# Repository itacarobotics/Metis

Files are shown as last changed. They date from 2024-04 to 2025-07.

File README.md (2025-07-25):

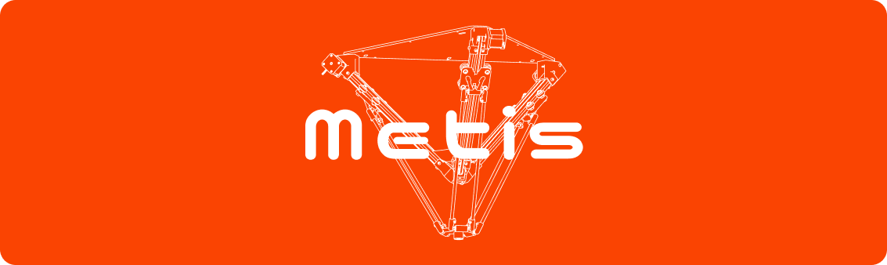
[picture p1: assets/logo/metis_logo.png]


# About
Welcome to the Metis repository! This project is dedicated to the design, manufacture, and control of a delta robot, entirely from scratch.

# Key Features
- *Custom 3D Printed Components*
- *URDF Description of the robot*
- *ROS2 Integration*
- *Micro-ROS on ESP32*

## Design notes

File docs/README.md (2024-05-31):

# Documentation

## Mechanics
All mechanical components have been designed from scratch using computer-aided design (CAD) software, specifically Autodesk Inventor 2024. Additionally, some components have been topological optimized with the software Autodesk Fusion. This process aims to optimize the material layout of mechanical components, reducing mass while increasing stiffness.

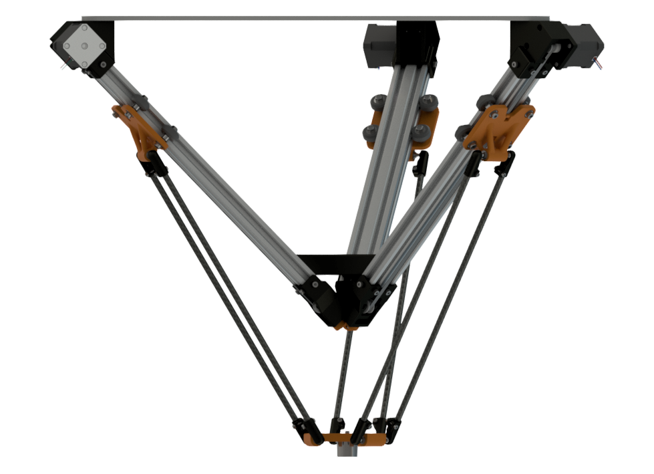
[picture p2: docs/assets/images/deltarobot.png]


#### Actuation
Industrial delta robots commonly have a revolute actuation, which enables fast movements at the cost of larger motors, given the mechanical disadvantage of a longer arm. For this project, the actuation is performed with belt-driven prismatic joints. This design choice allows for a more compact and cost-effective drivetrain, maintaining rigidity and precision.

#### Prismatic Joints
Designing the linear rails of the prismatic joint presented one of the biggest challenges in the mechanical design process. Traditional options like linear ball bearings and linear bearing rails were deemed too heavy and expensive, while polymeric bushings introduced excessive friction. The solution implemented is a rail system with four V-shaped profile wheels rolling within the cavities of an aluminum profile, a mechanism commonly found in 3D printers. This system ensures smooth and stiff motion.

#### Spherical Joints
Each prismatic joint features two spherical pins bolted onto a threaded aluminum shaft. These shafts are held in place by a topologically optimized structure, enhancing both weight distribution and stiffness. A spherical joint, designed to fit with minimal clearance onto the spherical pin, is manufactured using resin additive manufacturing for a refined surface finish, as opposed to Fusion Deposition Modeling (FDM) technology.

#### Workspace
While designing an industrial robot, it is essential to define its workspace. The total working volume that the end-effector can reach is directly influenced by the lengths of the robot's links and the strokes of its joints. To establish the kinematic properties of the robot, a Python script has been created to visualize the workspace of the delta robot.

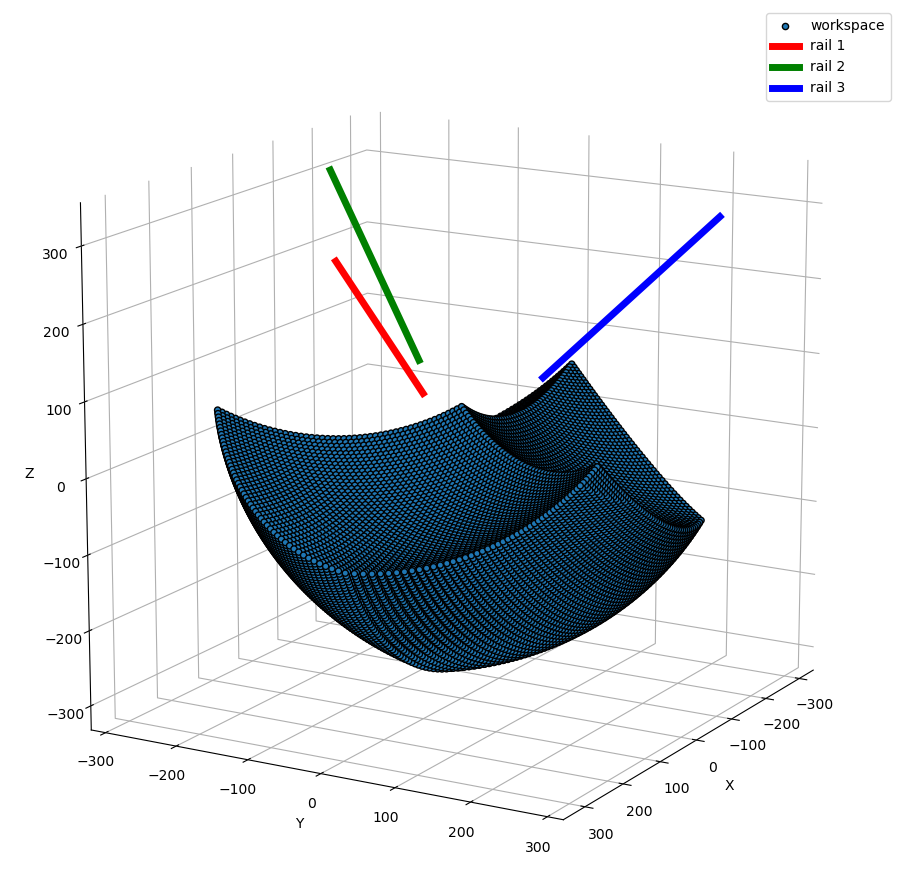
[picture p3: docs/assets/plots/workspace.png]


## Electronics
The electronics bridges the gap between the high level control system and the mechanics. The motherboard of the robot communicates to the computer (master) via USB or WIFI and directly controls all sensors, actuators and other peripherals of the robot.
Given limited time for the development of this project, an open-source motherboard ([MKS-DLC32](https://github.com/makerbase-mks/MKS-DLC32)), developed for desktop engraving machines, has been implemented.

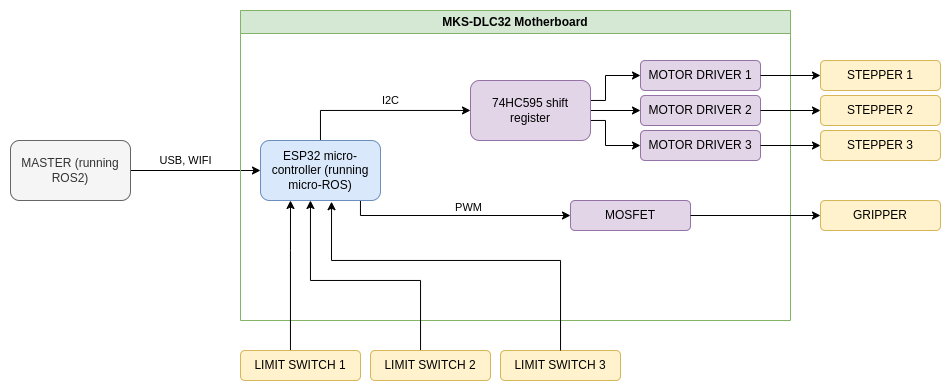
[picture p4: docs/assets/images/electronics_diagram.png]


#### Micro-controller
The ESP32 micro-controller is a low-power micro-controller. However, given its limited computational power, its main task is just to execute robot commands received by the main computer and directly control the low-level interfaces.

#### Motors and Motor Driver
The micro-controller has limited GPIO (General Pourpose Input Output). To solve this problem, the motherboard controls the stepper motor drivers with a shift register IO expander (74HC595). Stepper motors used for this project are NEMA17 with 60 Ncm of torque, which satisfy the project requirements.

#### Other Peripherals
The motherboard includes several peripheral interfaces essential for the robot's functionality. These peripherals include ports for limit switches and a MOSFET (Metal-Oxide-Semiconductor Field-Effect Transistor). Limit switches are used to set the zero position of the robot, when turned on. The MOSFET is integrated to enable and disable the electromagnetic gripper from the micro-controller.

## Software Architecture
The software of the delta robot is decentralized over two devices, the main computer, which is responsible for the heavier computational tasks and the micro-controller, which is responsible for controlling actuators, reading sensors and other peripherals. Overall the software architecture can be subdivided into three main sections

- High-level interfaces
- Robot controller middle-ware
- Low-level firmware

#### High-Level Interface
The high-level interface is composed of all nodes the user can use to interact with the robot. For instance, the graphical user interface (GUI) helps the user control the position of the robot or, open and close the gripper. Another useful method for programming tasks of an industrial robot is the G-Code. It is a language commonly used for CNC machines or 3D printers and it consists of a set of instruction that the robot has to execute. Furthermore, computer vision algorithms can be implemented for an automated pick and place application.

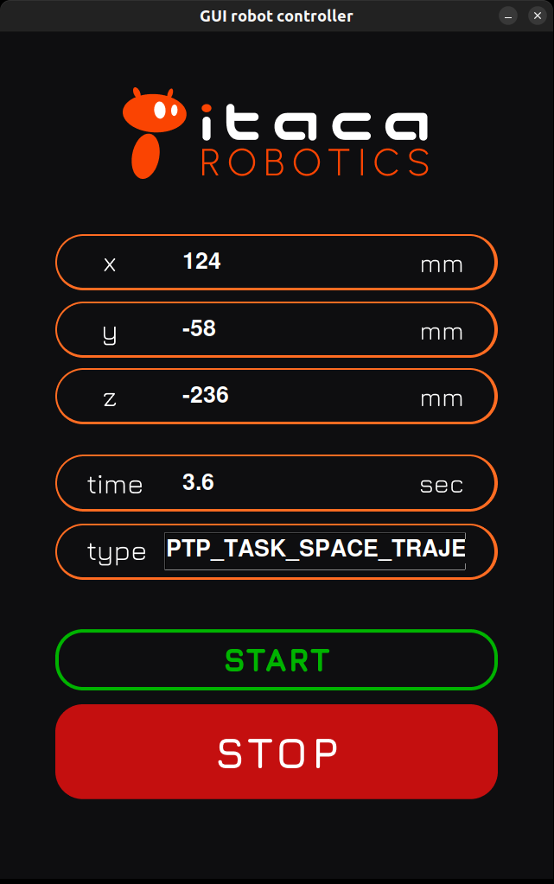
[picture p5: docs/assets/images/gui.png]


#### Middle-Ware
The middle-ware robot controller is mainly responsible for handling incoming tasks, managing exceptions and computing trajectory planning and inverse geometry. It is made up of the "task scheduler" and the "robot controller" ROS2 nodes. The first one takes all incoming tasks from the high-level interfaces and add them to a queue. Once the robot is ready, the task scheduler sends a new task from the queue to the robot controller node. This last computes the robot movements needed to accomplish the desired task and sends them to the micro-controller via USB or WIFI.

#### Low-Level Firmware
The low-level firmware runs on an ESP32 micro-controller and is mainly responsible for executing commands sent by the robot controller node. In order to integrate the micro-controller with the ROS2 environment, the firmware has been developed using the micro-ROS framework.
The micro-controller directly controls the stepper motors, the gripper and reads the state of the limit switches. After having completed the task, the micro-controller sends an acknowledgment (ack) feedback to the robot controller node, which accordingly sets the new state of the robot.

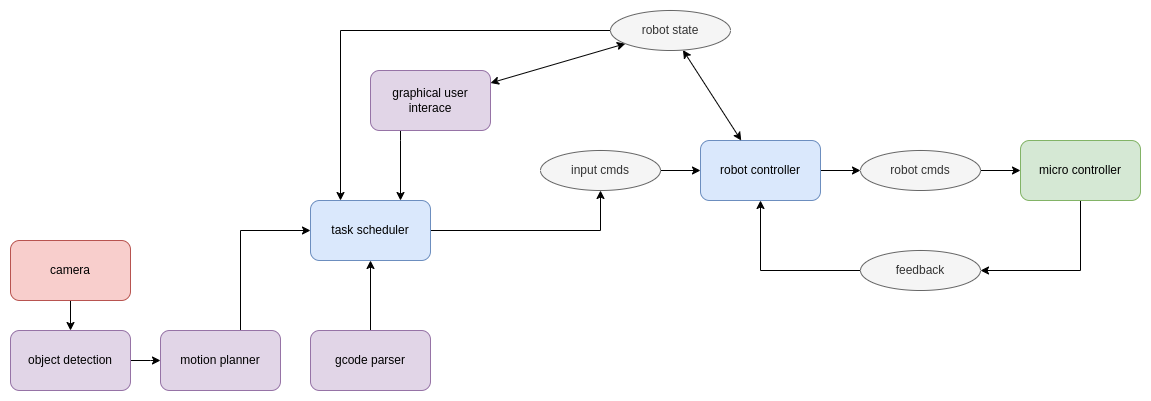
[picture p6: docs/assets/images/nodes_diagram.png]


## Trajectory Planning
For trajectories planned in task space, the path of the end-effector is interpolated with multiple via-points, whose the robot follows along its movement.
For this project, the path has been linearly interpolated by the function $\theta(s)$, hence the path describes a straight line from $X_0$ to $X_f$

$\theta(s) = X_0 + s \cdot (X_f-X_0), \qquad s \in [0, 1]$

The parameter $s$ is then remapped to a time scaling function in order to better control velocity and its derivatives along the path. The function $s(t)$ is interpolated with a fifth-order polynomial

$q(t) = a_0 + a_1 \cdot t + a_2 \cdot t^2 + a_3 \cdot t^3 + a_4 \cdot t^4 + a_5 \cdot t^5 \qquad t \in [0, T_f]$

In this case, the system of differential equations is

$q(0) = 0, \quad \dot{q}(0) = 0, \quad \ddot{q}(0) = 0 $
$q(T_f) = 1, \quad \dot{q}(T_f) = 0, \quad \ddot{q}(T_f) = 0 $

The closed form solution is

$a_0 = q_0, \quad a_1 = 0, \quad a_2 = 0 $
$a_3 =  \frac{10}{{T_f^3}}, \quad a_4 =  -\frac{15}{{T_f^4}}, \quad a_5 =  \frac{6}{{T_f^5}}$

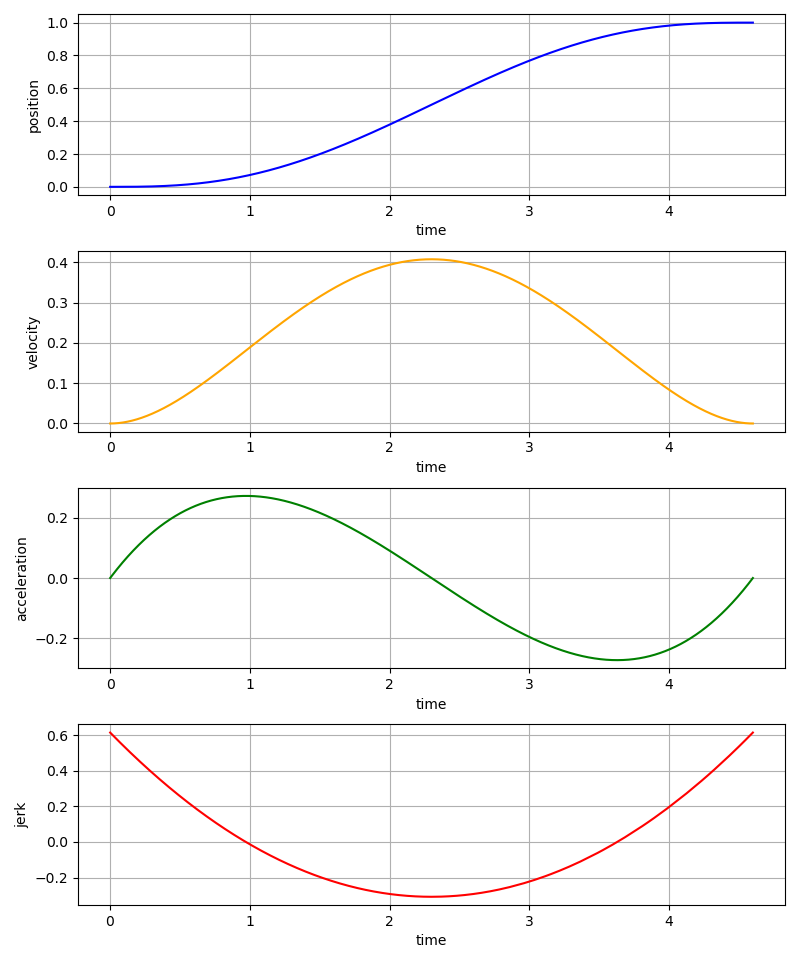
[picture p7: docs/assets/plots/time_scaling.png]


The total time of travel $T_f$ is calculated by setting joint's velocity and acceleration constraints.
Finally, inverse geometry is computed for each via point, resulting a joint trajectory.

## Inverse Geometry
The inverse geometry involves finding the joint angles that correspond to a desired end-effector position and orientation. 
The numerical inverse geometry of a delta robot, and many other robot arms, is a non linear optimization problem, which is solved over multiple iterations refining the initial guess for the joint angles, until a solution that minimizes the error between the desired and actual end-effector positions is found.
Overall, the problem admits a solution if the desired end-effector position is within the workspace of the robot. However, if a solution exists, there might be multiple or even infinite solutions.

In particular, if the problem admits a solution, it can be solved by minimizing the cost function $c(q)$, where, $f(q)$ is the forward geometry function and $p_d$ is the desired end-effector position. The goal is to find $q$ such that $f(q) \approx p_d$.

$c(q) = ||p_d - f(q)||$
For this project, the optimization problem has been solved with the Gauss-Newton algorithm, which starts with an initial guess $q_0$ and iterates as follows:

1. Compute the error vector  $e = p_d - f(q_i)$

2. Linearize the forward geometry function $f(q_i)$ around the current guess $q_i$ to obtain the Jacobian matrix $J(q_i)$.

3. Compute the step $\Delta q_i$ using the formula: 
$J^\dagger = J(q_i)^T J(q_i) + \lambda I, \quad \lambda \propto 10^{-2}$
$\Delta q_i = (J^\dagger)^{-1} J(q_i)^T e$

*Where* $J^\dagger$ *is the regularized pseudo-inverse of the Jacobian, which makes the matrix always invertible and positive.*

4. Update the guess:
$q_{i+1} = q_i + \Delta q_i$

5. Repeat steps 1-4 until convergence criteria are met, such as the error $||e||$ falling below a threshold or the change in $q_i$ falling below a threshold.

The cost function is a non-convex function, which means, it has at least one minimum. However, the algorithm may converge to a local minimum depending on the initial guess and the characteristics of the problem.

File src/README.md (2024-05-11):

# How to navigate the code
## /src/deltarobot
Middle-ware nodes and classes, runs ROS2 (on laptop)
- configuration file
- robot controller (node)
    - delta robot (class)
        - inverse geometry (class)
        - trajectroy generator (class)
- task scheduler (node)

## /src/deltarobot_inputs
High-level nodes to interact with the robot, runs ROS2 (on laptop)
- graphical user interface (node)
- gcode parser (node)
- template (node), for adding new features

## /src/firmware_esp32
Low-level firmware, runs 
[micro-ROS](https://github.com/micro-ROS/micro_ros_platformio) 
(on ESP32 microcontroller)
- micro-ROS init
- callback functions
- stepper motors driver

## /src/deltarobot_description
URDF description of the robot
- complete robot description (for visualizer)
- single closed chain description (for inverse geometry)

## /src/deltarobot_utils
Deprecated as last update.

## /src/micro_ros_setup
Used to setup the micro-ROS environment 
([help](https://github.com/micro-ROS/micro_ros_platformio))
(on ESP32 microcontroller)

## /src/uros
The actual micro-ROS agent 
([help](https://github.com/micro-ROS/micro_ros_platformio))
(on ESP32 microcontroller)

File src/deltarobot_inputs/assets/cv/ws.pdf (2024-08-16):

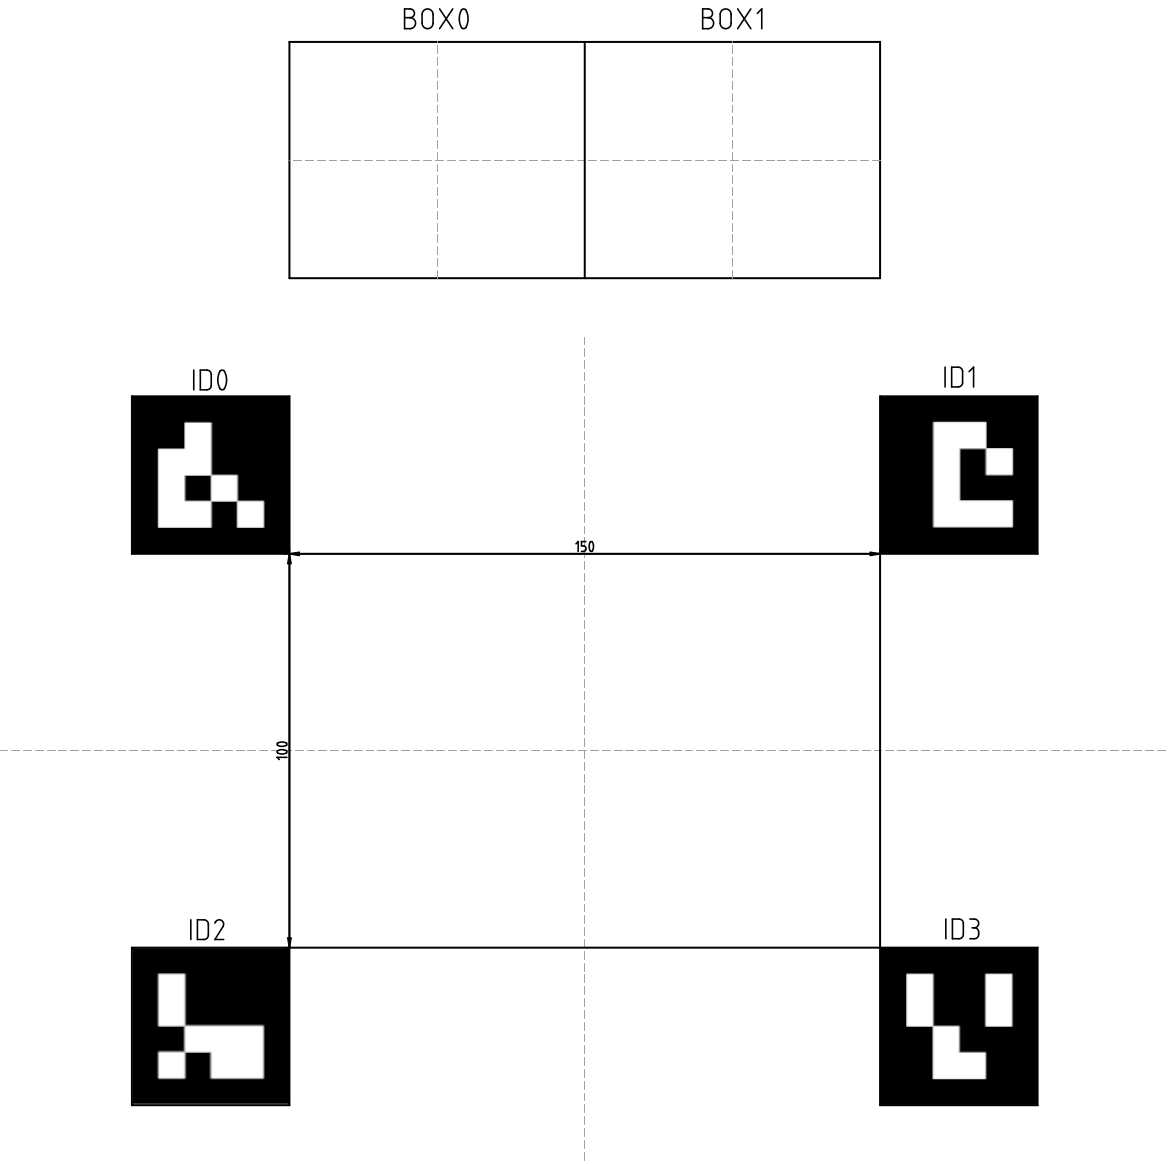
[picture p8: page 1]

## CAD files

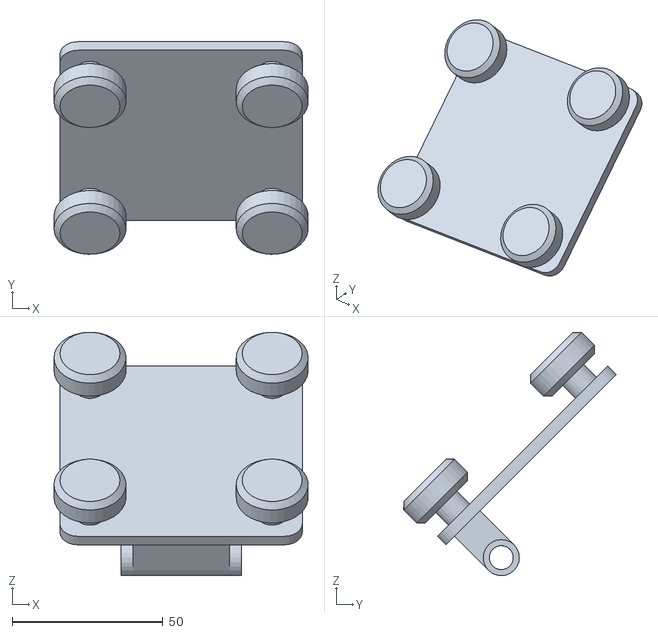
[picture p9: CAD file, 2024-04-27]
src/deltarobot_description/meshes/carriage.stl
84.3 x 70.6 x 80.8

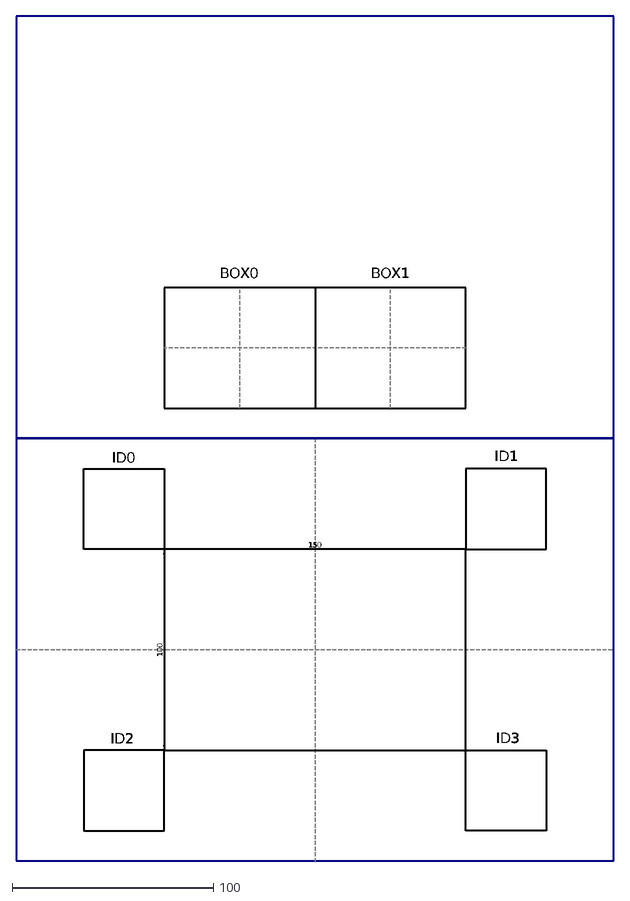
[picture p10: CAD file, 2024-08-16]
src/deltarobot_inputs/assets/cv/ws_base_A4.dxf
BOX0
BOX1
ID0
ID1
ID2
ID3
150
100

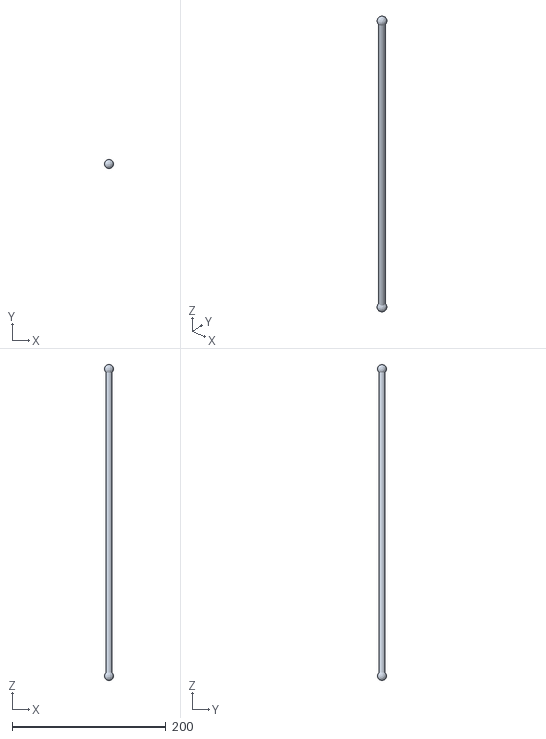
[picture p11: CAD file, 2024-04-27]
src/deltarobot_description/meshes/link.stl
12.0 x 11.4 x 411.7

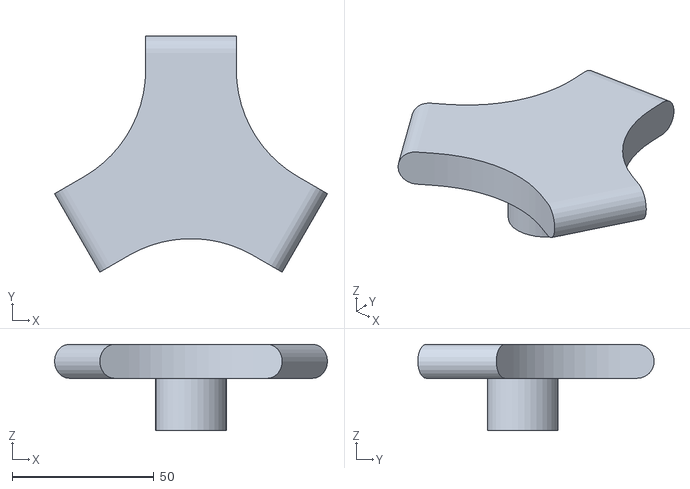
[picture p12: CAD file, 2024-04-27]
src/deltarobot_description/meshes/end_effector.stl
96.4 x 83.5 x 30.5

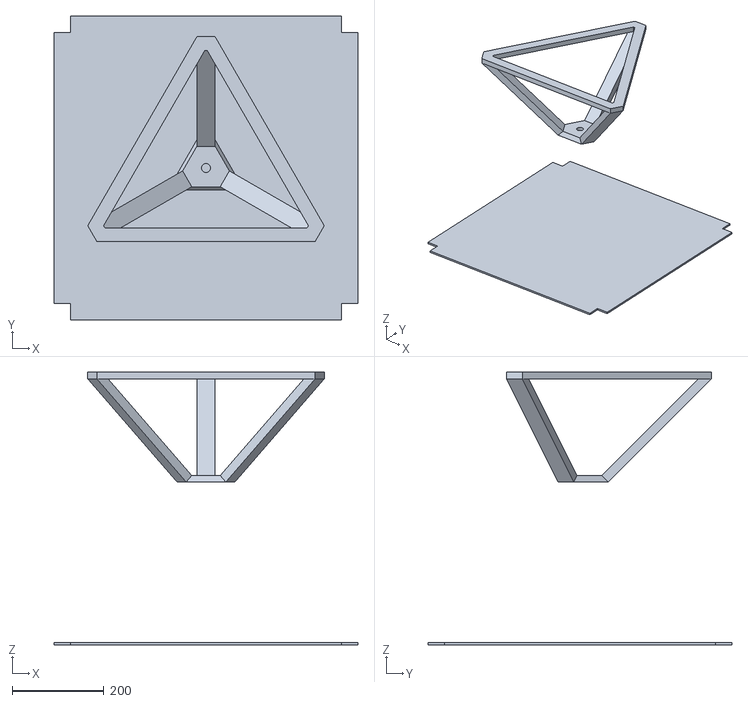
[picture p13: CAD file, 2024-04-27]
src/deltarobot_description/meshes/rails.stl
664.0 x 664.0 x 596.1

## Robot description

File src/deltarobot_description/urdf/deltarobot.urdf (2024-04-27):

<?xml version="1.0"?>
<robot name="deltarobot">

    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
    <link name="rails_link">
        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
    </link>
    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
    <link name="carriage_1_link">
        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
    </link>

    <joint name="carriage_1_joint" type="prismatic">
        <origin xyz="0. 0. 0." rpy="0 0 0"/>
        <parent link="rails_link"/>
        <child link="carriage_1_link"/>
        <axis xyz="0 1 1"/>
        <limit lower="0" upper="0" velocity="0" effort="0"/> 
    </joint>
    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
    <link name="rod_1a_link_virtual">
    </link>

    <link name="rod_1a_link">
        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
    </link>

    <joint name="rod_1a_x_joint" type="revolute">
        <origin xyz="25 0. 0." rpy="0 0 0"/>
        <parent link="carriage_1_link"/>
        <child link="rod_1a_link_virtual"/>
        <axis xyz="1 0 0"/>
        <limit lower="0" upper="0" velocity="0" effort="0"/> 
    </joint>

    <joint name="rod_1a_y_joint" type="revolute">
        <origin xyz="0. 0. 0." rpy="0 0 0"/>
        <parent link="rod_1a_link_virtual"/>
        <child link="rod_1a_link"/>
        <axis xyz="0 1 0"/>
        <limit lower="0" upper="0" velocity="0" effort="0"/> 
    </joint>
    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
    <link name="rod_1b_link_virtual">
    </link>

    <link name="rod_1b_link">
        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
    </link>

    <joint name="rod_1b_x_joint" type="revolute">
        <origin xyz="-25 0. 0." rpy="0 0 0"/>
        <parent link="carriage_1_link"/>
        <child link="rod_1b_link_virtual"/>
        <axis xyz="1 0 0"/>
        <limit lower="0" upper="0" velocity="0" effort="0"/> 
    </joint>

    <joint name="rod_1b_y_joint" type="revolute">
        <origin xyz="0. 0. 0." rpy="0 0 0"/>
        <parent link="rod_1b_link_virtual"/>
        <child link="rod_1b_link"/>
        <axis xyz="0 1 0"/>
        <limit lower="0" upper="0" velocity="0" effort="0"/> 
    </joint>
    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
    <link name="rod_1_end_effector_link">
    </link>

    <joint name="rod_1_end_effector_joint" type="fixed">
        <origin xyz="0 0 -400"/>
        <parent link="rod_1a_link"/>
        <child link="rod_1_end_effector_link"/>
    </joint>
    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
    <link name="carriage_2_link">
        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
    </link>

    <joint name="carriage_2_joint" type="prismatic">
        <origin xyz="0. 0. 0." rpy="0 0 0"/>
        <parent link="rails_link"/>
        <child link="carriage_2_link"/>
        <axis xyz="-0.61237244 -0.35355339 0.70710678"/>
        <limit lower="0" upper="0" velocity="0" effort="0"/> 
    </joint>
    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
    <link name="rod_2a_link_virtual">
    </link>

    <link name="rod_2a_link">
        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
    </link>

    <joint name="rod_2a_x_joint" type="revolute">
        <origin xyz="12.5 -21.650635 0" rpy="0 0 0"/>
        <parent link="carriage_2_link"/>
        <child link="rod_2a_link_virtual"/>
        <axis xyz="-0.5 0.8660254 0"/>
        <limit lower="0" upper="0" velocity="0" effort="0"/> 
    </joint>

    <joint name="rod_2a_y_joint" type="revolute">
        <origin xyz="0 0 0" rpy="0 0 0"/>
        <parent link="rod_2a_link_virtual"/>
        <child link="rod_2a_link"/>
        <axis xyz="-0.8660254 -0.5 0"/>
        <limit lower="0" upper="0" velocity="0" effort="0"/> 
    </joint>
    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
    <link name="rod_2b_link_virtual">
    </link>

    <link name="rod_2b_link">
        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
    </link>

    <joint name="rod_2b_x_joint" type="revolute">
        <origin xyz="-12.5 21.650635 0" rpy="0 0 0"/>
        <parent link="carriage_2_link"/>
        <child link="rod_2b_link_virtual"/>
        <axis xyz="-0.5 0.8660254 0"/>
        <limit lower="0" upper="0" velocity="0" effort="0"/> 
    </joint>

    <joint name="rod_2b_y_joint" type="revolute">
        <origin xyz="0 0 0" rpy="0 0 0"/>
        <parent link="rod_2b_link_virtual"/>
        <child link="rod_2b_link"/>
        <axis xyz="-0.8660254 -0.5 0"/>
        <limit lower="0" upper="0" velocity="0" effort="0"/> 
    </joint>
    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
    <link name="rod_2_end_effector_link">
    </link>

    <joint name="rod_2_end_effector_joint" type="fixed">
        <origin xyz="0 0 -400"/>
        <parent link="rod_2a_link"/>
        <child link="rod_2_end_effector_link"/>
    </joint>
    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
    <link name="carriage_3_link">
        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
    </link>

    <joint name="carriage_3_joint" type="prismatic">
        <origin xyz="0. 0. 0." rpy="0 0 0"/>
        <parent link="rails_link"/>
        <child link="carriage_3_link"/>
        <axis xyz="0.61237244 -0.35355339 0.70710678"/>
        <limit lower="0" upper="0" velocity="0" effort="0"/> 
    </joint>
    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
    <link name="rod_3a_link_virtual">
    </link>

    <link name="rod_3a_link">
        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
    </link>

    <joint name="rod_3a_x_joint" type="revolute">
        <origin xyz="-12.5 -21.650635 0" rpy="0 0 0"/>
        <parent link="carriage_3_link"/>
        <child link="rod_3a_link_virtual"/>
        <axis xyz="-0.5 -0.8660254 0"/>
        <limit lower="0" upper="0" velocity="0" effort="0"/> 
    </joint>

    <joint name="rod_3a_y_joint" type="revolute">
        <origin xyz="0 0 0" rpy="0 0 0"/>
        <parent link="rod_3a_link_virtual"/>
        <child link="rod_3a_link"/>
        <axis xyz="0.8660254 -0.5 0"/>
        <limit lower="0" upper="0" velocity="0" effort="0"/> 
    </joint>
    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
    <link name="rod_3b_link_virtual">
    </link>

    <link name="rod_3b_link">
        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
    </link>

    <joint name="rod_3b_x_joint" type="revolute">
        <origin xyz="12.5 21.650635 0" rpy="0 0 0"/>
        <parent link="carriage_3_link"/>
        <child link="rod_3b_link_virtual"/>
        <axis xyz="-0.5 -0.8660254 0"/>
        <limit lower="0" upper="0" velocity="0" effort="0"/> 
    </joint>

    <joint name="rod_3b_y_joint" type="revolute">
        <origin xyz="0 0 0" rpy="0 0 0"/>
        <parent link="rod_3b_link_virtual"/>
        <child link="rod_3b_link"/>
        <axis xyz="0.8660254 -0.5 0"/>
        <limit lower="0" upper="0" velocity="0" effort="0"/> 
    </joint>
    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
    <link name="rod_3_end_effector_link">
    </link>

    <joint name="rod_3_end_effector_joint" type="fixed">
        <origin xyz="0 0 -400"/>
        <parent link="rod_3a_link"/>
        <child link="rod_3_end_effector_link"/>
    </joint>
    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

</robot>

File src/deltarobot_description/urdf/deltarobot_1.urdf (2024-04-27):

<?xml version="1.0"?>
<robot name="deltarobot">

    <!-- RAILS -->
    <link name="rails_link">
        <visual>
            <origin xyz="0 0 0"/>
            <geometry>
                <mesh filename="rails.stl"/>
            </geometry>
            <material name="white">
              <color rgba="1 1 1 1"/>
            </material>
        </visual>
        <collision>
            <origin xyz="0 0 0"/>
            <geometry>
                <mesh filename="rails.stl"/>
            </geometry>
        </collision>
    </link>
    <!-- RAILS END-->

    <!-- ************************************************************************ -->

    <!-- CARRIAGE 1 -->
    <link name="carriage_1_link">
        <visual>
            <origin xyz="0 0 0"/>
            <geometry>
                <mesh filename="carriage.stl"/>
            </geometry>
            <material name="red">
              <color rgba="1 0 0 1"/>
            </material>
        </visual>
    </link>

    <joint name="carriage_1_joint" type="prismatic">
        <origin xyz="0 0 0" rpy="0 0 0"/>
        <parent link="rails_link"/>
        <child link="carriage_1_link"/>
        <axis xyz="0 1 1"/>
        <limit lower="0" upper="0" velocity="0" effort="0"/> 
    </joint>
    <!-- CARRIAGE 1 END-->


    <!-- ROD 1A -->
    <link name="rod_1a_link_virtual">
    </link>

    <link name="rod_1a_link">
        <visual>
            <origin xyz="0 0 0"/>
            <geometry>
                <mesh filename="link.stl"/>
            </geometry>
            <material name="red">
              <color rgba="1 0 0 1"/>
            </material>
        </visual>
        <collision>
            <origin xyz="0 0 0"/>
            <geometry>
                <mesh filename="link.stl"/>
            </geometry>
        </collision>
    </link>

    <joint name="rod_1a_x_joint" type="revolute">
        <origin xyz="0 0 0" rpy="0 0 0"/>
        <parent link="carriage_1_link"/>
        <child link="rod_1a_link_virtual"/>
        <axis xyz="1 0 0"/>
        <limit lower="0" upper="0" velocity="0" effort="0"/> 
    </joint>

    <joint name="rod_1a_y_joint" type="revolute">
        <origin xyz="0 0 0" rpy="0 0 0"/>
        <parent link="rod_1a_link_virtual"/>
        <child link="rod_1a_link"/>
        <axis xyz="0 1 0"/>
        <limit lower="0" upper="0" velocity="0" effort="0"/> 
    </joint>
    <!-- ROD 1A END-->

    <!-- ROD 1 END EFFECTOR -->
    <link name="rod_1_end_effector_link">
    </link>

    <joint name="rod_1_end_effector_joint" type="fixed">
        <origin xyz="0 0 -400"/>
        <parent link="rod_1a_link"/>
        <child link="rod_1_end_effector_link"/>
    </joint>
    <!-- ROD 1 END EFFECTOR END -->

</robot>

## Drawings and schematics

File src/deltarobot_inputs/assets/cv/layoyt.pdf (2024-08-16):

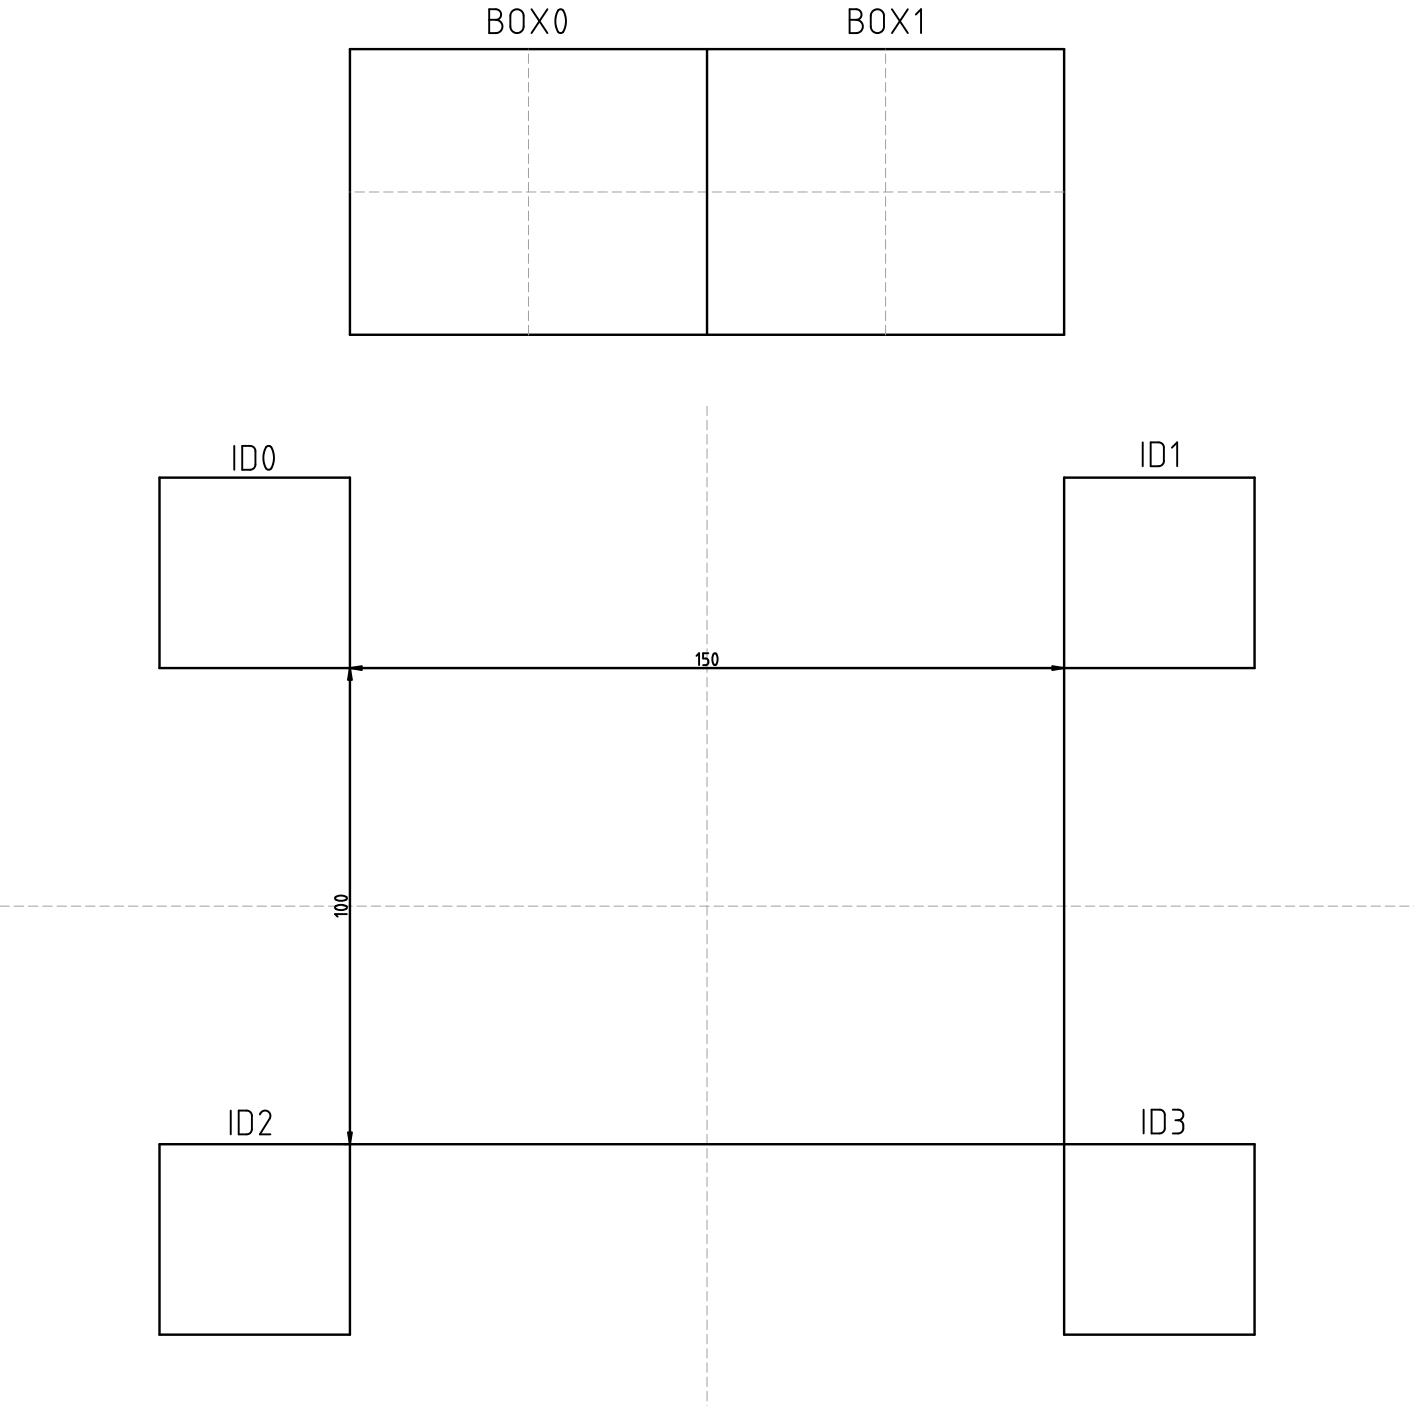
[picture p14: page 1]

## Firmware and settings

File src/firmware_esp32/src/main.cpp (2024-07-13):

#include <Arduino.h>
#include <micro_ros_platformio.h>

#include <rcl/rcl.h>
#include <rclc/rclc.h>
#include <rclc/executor.h>

#include "board_pinout.h"
#include "motor_driver/motor_driver.h"
#include "error_log/error_log.h"
#include "uros_subscribers/callback_functions.h"
#include "uros_publishers/uros_publishers.h"

#include "robot_interfaces.h"

void setup()
{
  // configure wifi transport
  // IPAddress agent_ip(192, 168, 113, 175);
  // size_t agent_port = 8888;
  // char ssid[] = "Laptop di Fede";
  // char psk[] = "12345678";
  // set_microros_wifi_transports(ssid, psk, agent_ip, agent_port);

  // configure serial transport
  Serial.begin(115200);
  set_microros_serial_transports(Serial);
  delay(500);

  // initialize shift register pinout
  pinMode(I2S_DATA_PIN, OUTPUT);
  pinMode(I2S_CLOCK_PIN, OUTPUT);
  pinMode(I2S_LATCH_PIN, OUTPUT);

  // initialize limit switches pinout
  pinMode(LIMIT_SWITCH_1_PIN, INPUT);
  pinMode(LIMIT_SWITCH_2_PIN, INPUT);
  pinMode(LIMIT_SWITCH_3_PIN, INPUT);

  // initialize gripper pinout
  // ...

  // micro-ROS setup
  rcl_allocator_t allocator = rcl_get_default_allocator();
  rclc_support_t support;

  // create init_options
  RCCHECK(rclc_support_init(&support, 0, NULL, &allocator));

  // create node
  rcl_node_t node;
  RCCHECK(rclc_node_init_default(&node, "micro_controller_node", "", &support));

  // create executor
  rclc_executor_t executor = rclc_executor_get_zero_initialized_executor();
  RCCHECK(rclc_executor_init(&executor, &support.context,
                             3,  // number of subscribers, timers, ...
                             &allocator));

  /********************************************************************************************************************
   *
   *                            ll_robot_cmds/move/joint_trajectory subscriber
   *
   ********************************************************************************************************************/
  rcl_subscription_t ll_robot_cmds__move__joint_trajectory__sub;
  RCCHECK(rclc_subscription_init_default(&ll_robot_cmds__move__joint_trajectory__sub, &node,
                                         ROSIDL_GET_MSG_TYPE_SUPPORT(micro_custom_messages, msg, JointTrajectoryArray),
                                         "ll_robot_cmds/move/joint_trajectory"));

  // allocate message memory
  micro_custom_messages__msg__JointTrajectoryArray via_points_array_msg;  // allocate message memory
  via_points_array_msg.array_size = 400;                                  // max capacity
  via_points_array_msg.via_points.capacity = via_points_array_msg.array_size;
  via_points_array_msg.via_points.data = (micro_custom_messages__msg__JointTrajectory*)malloc(
      via_points_array_msg.via_points.capacity * sizeof(micro_custom_messages__msg__JointTrajectory));
  via_points_array_msg.via_points.size = 0;

  // add subscription to topic
  RCCHECK(rclc_executor_add_subscription(&executor, &ll_robot_cmds__move__joint_trajectory__sub, &via_points_array_msg,
                                         &ll_robot_cmds__move__joint_trajectory__callback, ON_NEW_DATA));

  /********************************************************************************************************************
   *
   *                                    ll_robot_cmds/homing SUBSCRIBER
   *
   ********************************************************************************************************************/
  rcl_subscription_t ll_robot_cmds__homing__sub;
  RCCHECK(rclc_subscription_init_default(&ll_robot_cmds__homing__sub, &node,
                                         ROSIDL_GET_MSG_TYPE_SUPPORT(std_msgs, msg, Bool), "ll_robot_cmds/homing"));

  // allocate message memory
  std_msgs__msg__Bool ll_robot_cmds__homing__msg;

  // add subscription to topic
  RCCHECK(rclc_executor_add_subscription(&executor, &ll_robot_cmds__homing__sub, &ll_robot_cmds__homing__msg,
                                         &ll_robot_cmds__homing__callback, ON_NEW_DATA));

  /********************************************************************************************************************
   *
   *                                    ll_robot_cmds/gripper/em SUBSCRIBER
   *
   ********************************************************************************************************************/
  rcl_subscription_t ll_robot_cmds__gripper__em__sub;
  RCCHECK(rclc_subscription_init_default(&ll_robot_cmds__gripper__em__sub, &node,
                                         ROSIDL_GET_MSG_TYPE_SUPPORT(std_msgs, msg, Bool), "ll_robot_cmds/gripper/em"));

  // allocate message memory
  std_msgs__msg__Bool ll_robot_cmds__gripper__em__msg;

  // add subscription to topic
  RCCHECK(rclc_executor_add_subscription(&executor, &ll_robot_cmds__gripper__em__sub, &ll_robot_cmds__gripper__em__msg,
                                         &ll_robot_cmds__gripper__em__callback, ON_NEW_DATA));

  /********************************************************************************************************************
   *
   *                                    feedback/task_ack PUBLISHER
   *
   ********************************************************************************************************************/
  RCCHECK(rclc_publisher_init_default(&feedback__task_ack__pub, &node, ROSIDL_GET_MSG_TYPE_SUPPORT(std_msgs, msg, Bool),
                                      "feedback/task_ack"));

  // spin the node
  rclc_executor_spin(&executor);  // loop*

  // destroy nodes
  RCCHECK(rcl_subscription_fini(&ll_robot_cmds__move__joint_trajectory__sub, &node));
  RCCHECK(rcl_subscription_fini(&ll_robot_cmds__homing__sub, &node));
  RCCHECK(rcl_subscription_fini(&ll_robot_cmds__gripper__em__sub, &node));
  RCCHECK(rcl_node_fini(&node));
  return;
}

void loop()
{
  // loop*
}

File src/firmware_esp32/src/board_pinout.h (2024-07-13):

#ifndef BOARD_PINOUT_H
#define BOARD_PINOUT_H

// shift register pinout
#define NUMBER_SHIFT_REG 1
#define I2S_DATA_PIN 21
#define I2S_CLOCK_PIN 16
#define I2S_LATCH_PIN 17

// motor driver pinout
#define PIN_STEPPER_1_STEP 3  // 3
#define PIN_STEPPER_1_DIR 4   // 4

#define PIN_STEPPER_2_STEP 1  // 1
#define PIN_STEPPER_2_DIR 2   // 2

#define PIN_STEPPER_3_STEP 5  // 5
#define PIN_STEPPER_3_DIR 6   // 6

// limit switch pinout
#define LIMIT_SWITCH_1_PIN 36  // 36
#define LIMIT_SWITCH_2_PIN 34  // 34
#define LIMIT_SWITCH_3_PIN 35  // 35

// gripper pinout
#define ELECTRO_MAGNET_PIN 32

#endif  // BOARD_PINOUT_H

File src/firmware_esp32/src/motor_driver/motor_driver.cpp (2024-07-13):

#include "motor_driver.h"

ShiftRegister74HC595<NUMBER_SHIFT_REG> sr(I2S_DATA_PIN, I2S_CLOCK_PIN, I2S_LATCH_PIN);

MotorDriver::MotorDriver(void)
{
  // initialize stepper pins to LOW
  sr.set(PIN_STEPPERS_STEP[STEPPER1_IDX], PIN_STEPPERS_STEP__state[STEPPER1_IDX]);
  sr.set(PIN_STEPPERS_STEP[STEPPER2_IDX], PIN_STEPPERS_STEP__state[STEPPER2_IDX]);
  sr.set(PIN_STEPPERS_STEP[STEPPER3_IDX], PIN_STEPPERS_STEP__state[STEPPER3_IDX]);

  return;
}

void MotorDriver::toggle_stepper_step_tick(int stepper_index)
{
  if (PIN_STEPPERS_STEP__state[stepper_index] == LOW)
  {
    sr.set(PIN_STEPPERS_STEP[stepper_index], HIGH);
    PIN_STEPPERS_STEP__state[stepper_index] = HIGH;
  }
  else
  {
    sr.set(PIN_STEPPERS_STEP[stepper_index], LOW);
    PIN_STEPPERS_STEP__state[stepper_index] = LOW;
  }

  return;
}

void MotorDriver::set_direction(char PIN_STEPPER_X_DIR, float sign)
{
  if (sign < 0)
  {
    sr.set(PIN_STEPPER_X_DIR, HIGH);
  }
  else
  {
    sr.set(PIN_STEPPER_X_DIR, LOW);
  }
  return;
}

int MotorDriver::get_total_stepper_ticks(float delta_q_mm, int stepper_index)
{
  int stepper_ticks_total;

  // adding error compensation
  // delta_q_mm += delta_q_remainder_mm[stepper_index];
  // calculating ticks, where two ticks are one (micro-)step
  stepper_ticks_total = 2.0F * delta_q_mm / MM_PER_STEP;

  // updating error compensation
  // delta_q_remainder_mm[stepper_index] = delta_q_mm - (0.5F * float(stepper_ticks_total) * MM_PER_STEP);

  return abs(stepper_ticks_total);
}

int MotorDriver::get_delay_stepper_ticks(int stepper_ticks_total, int delta_t_micros)
{
  int stepper_tick_delay_micros;

  if (stepper_ticks_total != 0)
  {  // avoid zero division
    stepper_tick_delay_micros = delta_t_micros / stepper_ticks_total;
  }
  else
  {
    stepper_tick_delay_micros = 0;
  }

  return stepper_tick_delay_micros;
}

/*
    moving three stepper motors at different speeds in same interval of time.
*/
void MotorDriver::move_steppers_async(float delta_q1_mm, float delta_q2_mm, float delta_q3_mm, int delta_t_micros)
{
  // stepper 1
  set_direction(PIN_STEPPER_1_DIR, -delta_q1_mm);
  int stepper1_ticks_counter = 1;
  int stepper1_ticks_total = get_total_stepper_ticks(delta_q1_mm, STEPPER1_IDX);
  int stepper1_tick_delay_micros = get_delay_stepper_ticks(stepper1_ticks_total, delta_t_micros);

  // stepper 2
  set_direction(PIN_STEPPER_2_DIR, delta_q2_mm);
  int stepper2_ticks_counter = 1;
  int stepper2_ticks_total = get_total_stepper_ticks(delta_q2_mm, STEPPER2_IDX);
  int stepper2_tick_delay_micros = get_delay_stepper_ticks(stepper2_ticks_total, delta_t_micros);

  // stepper 3
  set_direction(PIN_STEPPER_3_DIR, delta_q3_mm);
  int stepper3_ticks_counter = 1;
  int stepper3_ticks_total = get_total_stepper_ticks(delta_q3_mm, STEPPER3_IDX);
  int stepper3_tick_delay_micros = get_delay_stepper_ticks(stepper3_ticks_total, delta_t_micros);

  /**********************************************************
   *                      CONTROL STEPPERS
   **********************************************************/

  int time_dt = 0;
  int initial_time = micros();

  while (true)
  {
    time_dt = micros() - initial_time;

    // stepper 1
    if ((stepper1_ticks_counter <= stepper1_ticks_total) &&
        (time_dt >= stepper1_tick_delay_micros * stepper1_ticks_counter))
    {
      toggle_stepper_step_tick(STEPPER1_IDX);
      stepper1_ticks_counter += 1;
    }

    // stepper 2
    else if ((stepper2_ticks_counter <= stepper2_ticks_total) &&
             (time_dt >= stepper2_tick_delay_micros * stepper2_ticks_counter))
    {
      toggle_stepper_step_tick(STEPPER2_IDX);
      stepper2_ticks_counter += 1;
    }

    // stepper 3
    else if ((stepper3_ticks_counter <= stepper3_ticks_total) &&
             (time_dt >= stepper3_tick_delay_micros * stepper3_ticks_counter))
    {
      toggle_stepper_step_tick(STEPPER3_IDX);
      stepper3_ticks_counter += 1;
    }

    if ((stepper1_ticks_counter > stepper1_ticks_total) && (stepper2_ticks_counter > stepper2_ticks_total) &&
        (stepper3_ticks_counter > stepper3_ticks_total))
    {
      break;
    }
  }

  return;
}

void MotorDriver::homing(void)
{
  bool is_homing_1 = true;
  bool is_homing_2 = true;
  bool is_homing_3 = true;

  set_direction(PIN_STEPPER_1_DIR, -1.0F);
  set_direction(PIN_STEPPER_2_DIR, 1.0F);
  set_direction(PIN_STEPPER_3_DIR, 1.0F);

  while (true)
  {
    // if all limit switches are pressed
    if (!is_homing_1 && !is_homing_2 && !is_homing_3)
    {
      break;
    }

    // check if limit switch is pressed
    if (analogRead(LIMIT_SWITCH_1_PIN) > 0)
    {
      is_homing_1 = false;
    }
    if (analogRead(LIMIT_SWITCH_2_PIN) > 0)
    {
      is_homing_2 = false;
    }
    if (analogRead(LIMIT_SWITCH_3_PIN) > 0)
    {
      is_homing_3 = false;
    }

    // do half step
    if (is_homing_1)
    {
      toggle_stepper_step_tick(STEPPER1_IDX);
    }
    if (is_homing_2)
    {
      toggle_stepper_step_tick(STEPPER2_IDX);
    }
    if (is_homing_3)
    {
      toggle_stepper_step_tick(STEPPER3_IDX);
    }

    // wait
    delayMicroseconds(700);
  }

  delay(500);

  // go back by default offset
  set_direction(PIN_STEPPER_1_DIR, 1.0F);
  set_direction(PIN_STEPPER_2_DIR, -1.0F);
  set_direction(PIN_STEPPER_3_DIR, -1.0F);

  for (int i = 0; i < 300; ++i)
  {
    toggle_stepper_step_tick(STEPPER1_IDX);
    toggle_stepper_step_tick(STEPPER2_IDX);
    toggle_stepper_step_tick(STEPPER3_IDX);
    delayMicroseconds(700);
  }

  return;
}

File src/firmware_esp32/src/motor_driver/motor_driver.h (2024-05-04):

#ifndef MOTOR_DRIVER_H
#define MOTOR_DRIVER_H

#include "Arduino.h"
#include "ShiftRegister74HC595.h"
#include "board_pinout.h"

#define STEPPER1_IDX 0
#define STEPPER2_IDX 1
#define STEPPER3_IDX 2


class MotorDriver
{
    private:
        /*
            D = 12.22   --> pulley's pitch diameter
            steps_per_revolution = 200 * 8 = 1600   --> 1/8 microstepping
            MM_PER_STEP = pi*D / steps_per_revolution = pi*D / 1600

            pi*D : 1600 == MM_PER_STEP : 1
            MM_PER_STEP = pi*D*1 / 1600

            MM_PER_STEP = pi*12.22/1600 = 0.023993913891792

        */
        float MM_PER_STEP = 0.02519075648F;
        
        float delta_q_remainder_mm[3]   = {0.0, 0.0, 0.0};
        int PIN_STEPPERS_STEP[3]        = {PIN_STEPPER_1_STEP, PIN_STEPPER_2_STEP, PIN_STEPPER_3_STEP};
        int PIN_STEPPERS_STEP__state[3] = {LOW, LOW, LOW};

        int get_total_stepper_ticks(float delta_q, int stepper_index);
        int get_delay_stepper_ticks(int stepper_ticks_total, int delta_t_micros);
        
        void toggle_stepper_step_tick(int stepper_index);
        void set_direction(char PIN_STEPPER_X_STEP, float sign);


    public:
        MotorDriver();

        void move_steppers_async(   float delta_q1, 
                                    float delta_q2, 
                                    float delta_q3, 
                                    int delta_t_micros);
        void homing(void);

};

extern MotorDriver mdriver;

#endif  // MOTOR_DRIVER_H
